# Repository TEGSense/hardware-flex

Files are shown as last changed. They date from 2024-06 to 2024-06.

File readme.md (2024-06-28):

# TEG Sense Board

This is a thermoelectric generator (TEG) boost converter used to power a connected battery or capacitor to periodically operate a microcontroller reading from a biometric sensor to compute blood oxygen saturation. That was a big sentence!

This is the second iteration of the TEGSense board, with some schematic fixes and redesigned for a smaller flex board with bigger contacts for easy printing of conductive traces.
It is intended to be connected to a print-friendly version of the [SpO2 board](https://github.com/TEGSense/hardware-spo2-flex) and a [flex capacitor bank](https://github.com/TEGSense/hardware-flex-capboard).

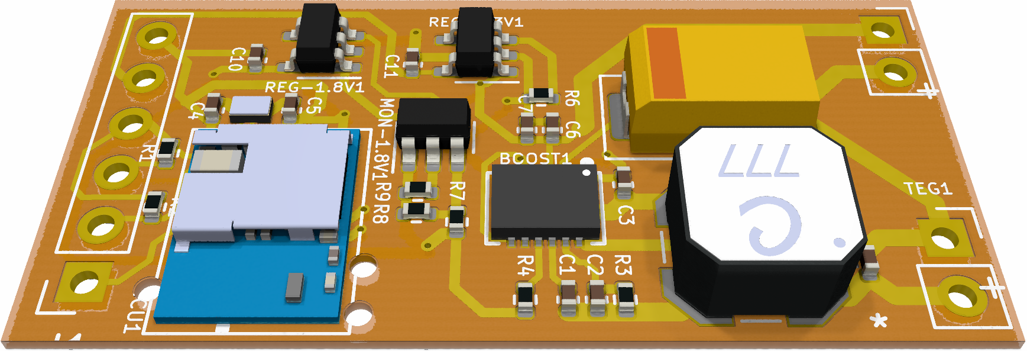
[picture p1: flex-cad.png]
CAD rendering


## License

Shield: [][cc-by-sa]

This work is licensed under a
[Creative Commons Attribution-ShareAlike 4.0 International License][cc-by-sa].

[][cc-by-sa]

[cc-by-sa]: http://creativecommons.org/licenses/by-sa/4.0/
[cc-by-sa-image]: https://licensebuttons.net/l/by-sa/4.0/88x31.png
[cc-by-sa-shield]: https://img.shields.io/badge/License-CC%20BY--SA%204.0-lightgrey.svg

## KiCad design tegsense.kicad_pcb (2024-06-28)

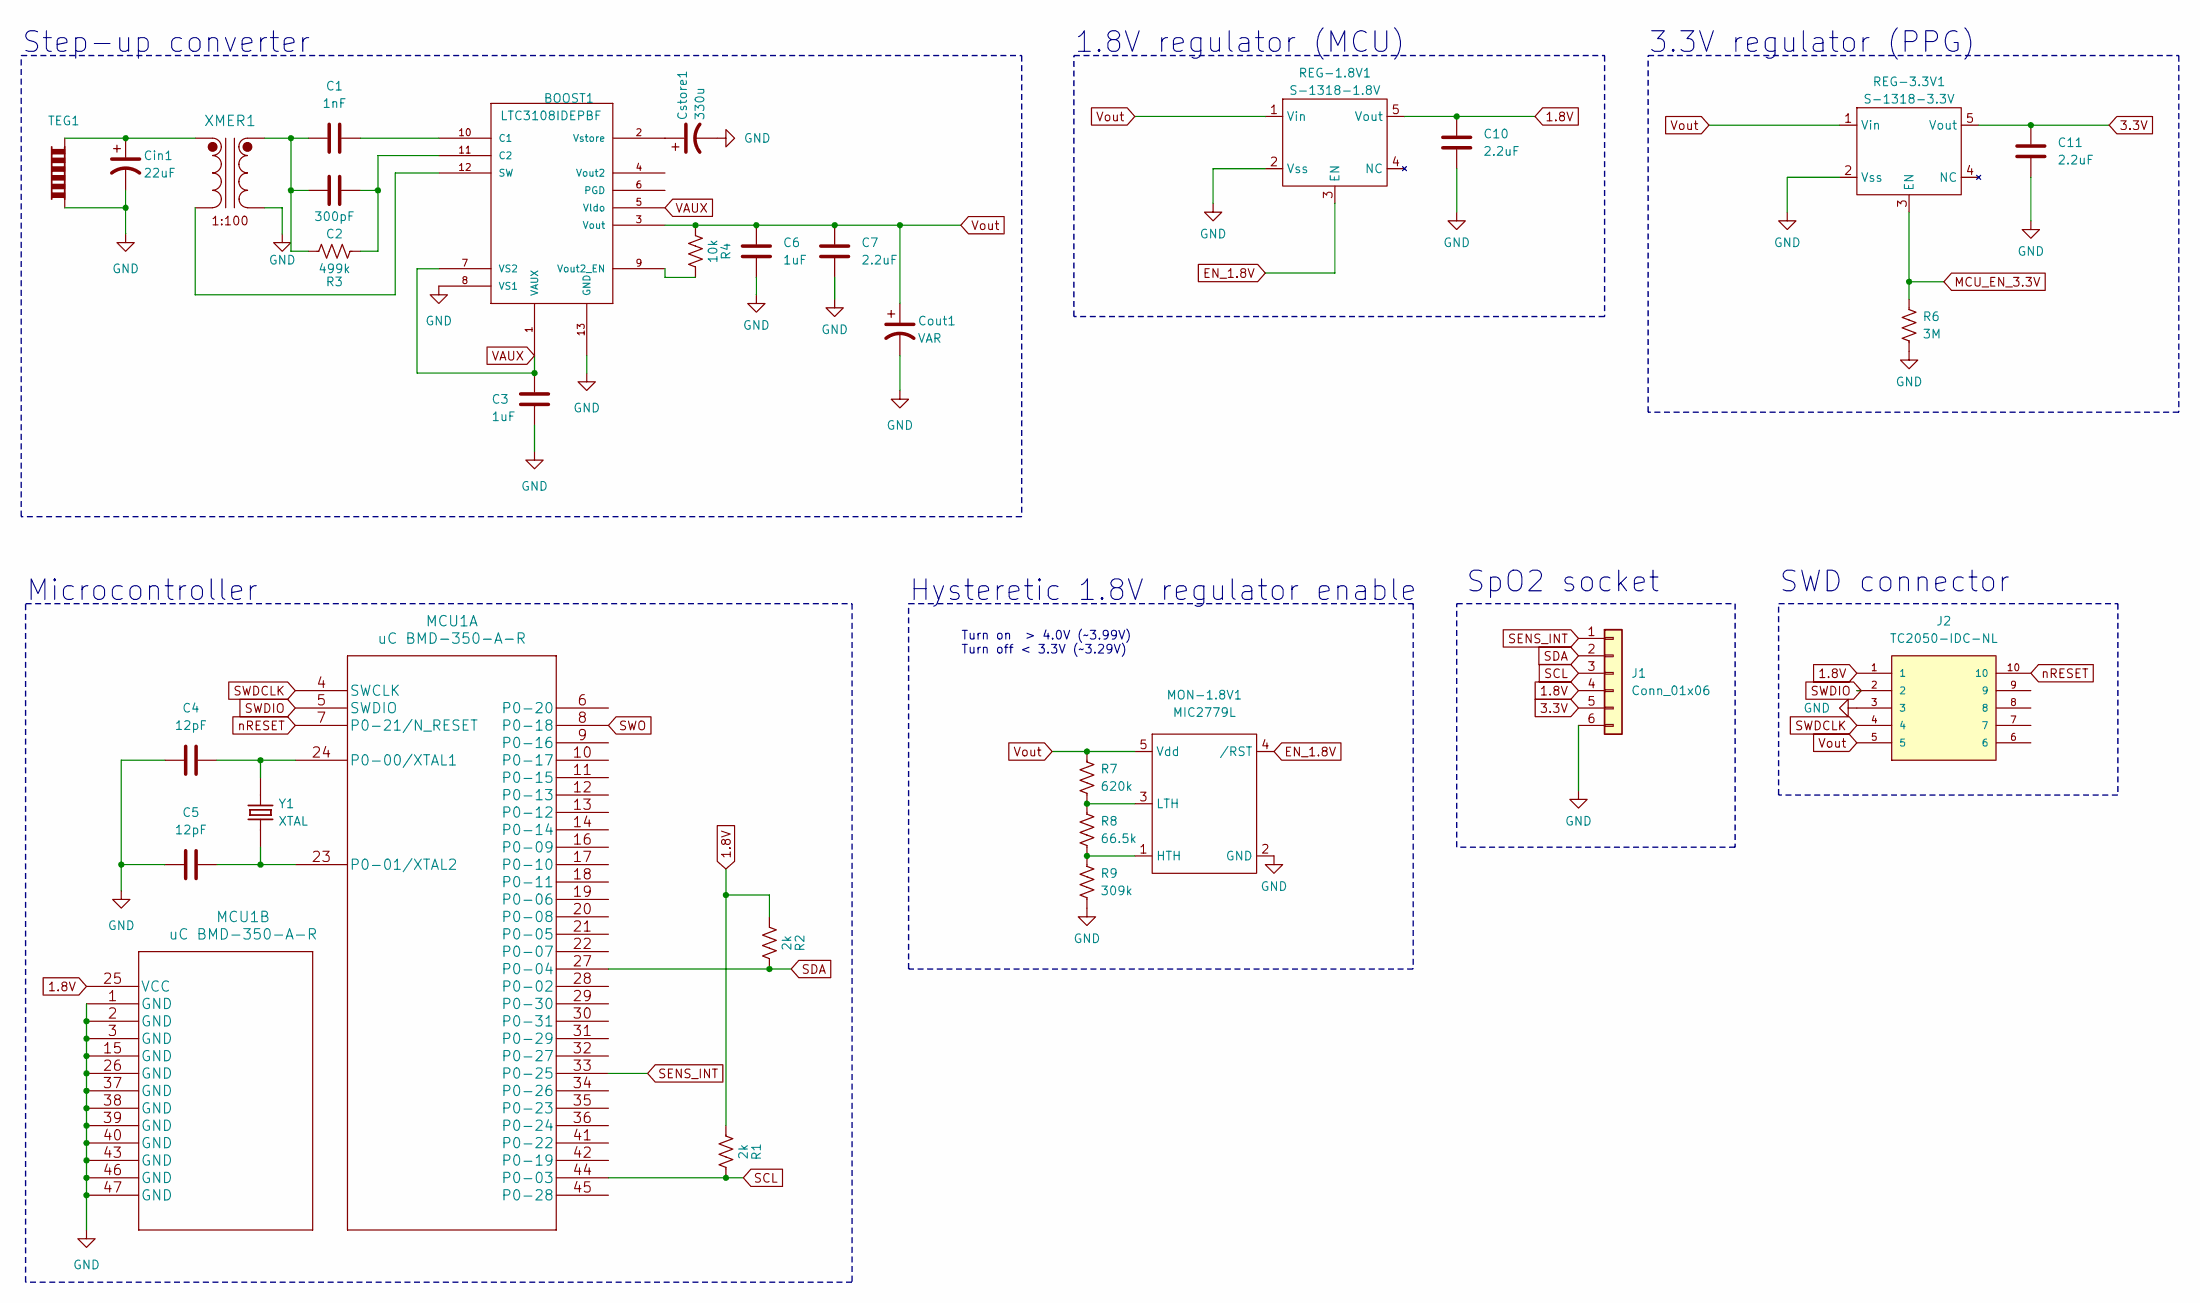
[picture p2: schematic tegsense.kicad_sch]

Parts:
BOOST1: LTC3108IDEPBF; DFN-12_DE
C1: 1nF; C_0402_1005Metric
C2: 300pF; C_0402_1005Metric
C3, C6: 1uF; C_0402_1005Metric
C4, C5: 12pF; C_0402_1005Metric
C7, C10, C11: 2.2uF; C_0402_1005Metric
Cin1: 22uF; C_0402_1005Metric
Cout1: VAR; PinSocket_1x02_P2.54mm_Vertical
Cstore1: 330u; CP_EIA-7343-31_Kemet-D
J1: Conn_01x06; PinSocket_1x06_P2.54mm_Vertical
J2: TC2050-IDC-NL
MCU1: uC BMD-350-A-R; BMD-350-A-R
MON-1.8V1: MIC2779L; SOT-23-5
R1, R2: 2k; R_0402_1005Metric
R3: 499k; R_0402_1005Metric
R4: 10k; R_0402_1005Metric
R6: 3M; R_0402_1005Metric
R7: 620k; R_0402_1005Metric
R8: 66.5k; R_0402_1005Metric
R9: 309k; R_0402_1005Metric
REG-1.8V1: S-1318-1.8V; SOT-23-5
REG-3.3V1: S-1318-3.3V; SOT-23-5
TEG1: TEG; PinSocket_1x02_P2.54mm_Vertical
XMER1: LPR6235-752SMLC
Y1: XTAL; XTAL_ECS-.327-9-16-TR

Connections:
1.8V: C10.1, J1.4, J2.1, MCU1.25 (VCC), R1.1, R2.1, REG-1.8V1.5 (Vout)
3.3V: C11.1, J1.5, REG-3.3V1.5 (Vout)
EN_1.8V: MON-1.8V1.4 (/RST), REG-1.8V1.3 (EN)
GND: BOOST1.8 (VS1), BOOST1.13 (GND), C3.2, C4.1, C5.1, C6.1, C7.2, C10.2, C11.2, Cin1.2, Cout1.2, Cstore1.2, J1.6, J2.3, MCU1.1 (GND), MCU1.2 (GND), MCU1.3 (GND), MCU1.15 (GND), MCU1.26 (GND), MCU1.37 (GND), MCU1.38 (GND), MCU1.39 (GND), MCU1.40 (GND), MCU1.43 (GND), MCU1.46 (GND), MCU1.47 (GND), MON-1.8V1.2 (GND), R6.2, R9.2, REG-1.8V1.2 (Vss), REG-3.3V1.2 (Vss), TEG1.1, XMER1.3
MCU_EN_3.3V: R6.1, REG-3.3V1.3 (EN)
unnamed: BOOST1.2 (Vstore), Cstore1.1
unnamed: BOOST1.9 (Vout2_EN), R4.2
unnamed: BOOST1.10 (C1), C1.2
unnamed: BOOST1.11 (C2), C2.2, R3.2
unnamed: BOOST1.12 (SW), XMER1.2
unnamed: C1.1, C2.1, R3.1, XMER1.4
unnamed: C4.2, MCU1.24 (P0-00/XTAL1), Y1.2
unnamed: C5.2, MCU1.23 (P0-01/XTAL2), Y1.1
unnamed: Cin1.1, TEG1.2, XMER1.1
unnamed: MON-1.8V1.1 (HTH), R8.2, R9.1
unnamed: MON-1.8V1.3 (LTH), R7.2, R8.1
SCL: J1.3, MCU1.44 (P0-03), R1.2
SDA: J1.2, MCU1.27 (P0-04), R2.2
SENS_INT: J1.1, MCU1.33 (P0-25)
SWDCLK: J2.4, MCU1.4 (SWCLK)
SWDIO: J2.2, MCU1.5 (SWDIO)
SWO: MCU1.8 (P0-18)
VAUX: BOOST1.1 (VAUX), BOOST1.5 (Vldo), BOOST1.7 (VS2), C3.1
Vout: BOOST1.3 (Vout), C6.2, C7.1, Cout1.1, J2.5, MON-1.8V1.5 (Vdd), R4.1, R7.1, REG-1.8V1.1 (Vin), REG-3.3V1.1 (Vin)
nRESET: J2.10, MCU1.7 (P0-21/N_RESET)

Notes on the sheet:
SWD connector
1.8V regulator (MCU)
Step-up converter
3.3V regulator (PPG)
Microcontroller
Turn on > 4.0V (~3.99V) Turn off < 3.3V (~3.29V)
Hysteretic 1.8V regulator enable
SpO2 socket

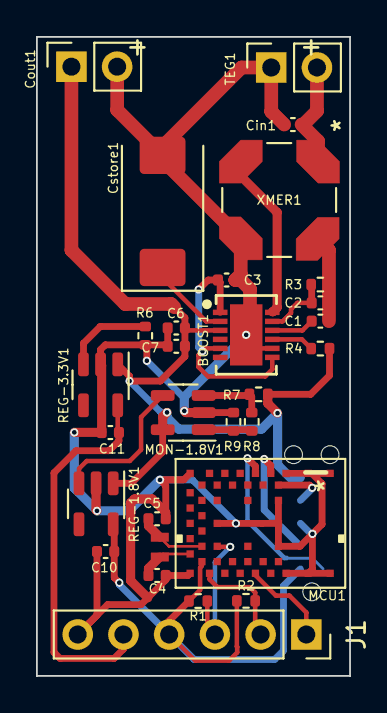
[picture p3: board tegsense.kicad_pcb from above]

Board: 2 copper layers, 17.4 x 35.5 mm, 30 parts (1 on the bottom side), 24 nets.
